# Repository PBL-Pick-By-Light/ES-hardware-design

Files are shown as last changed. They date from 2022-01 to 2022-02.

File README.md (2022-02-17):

# Hardware Design

## Introduction

Welcome to the hardware design repository of the Pick-by-Light projekt!

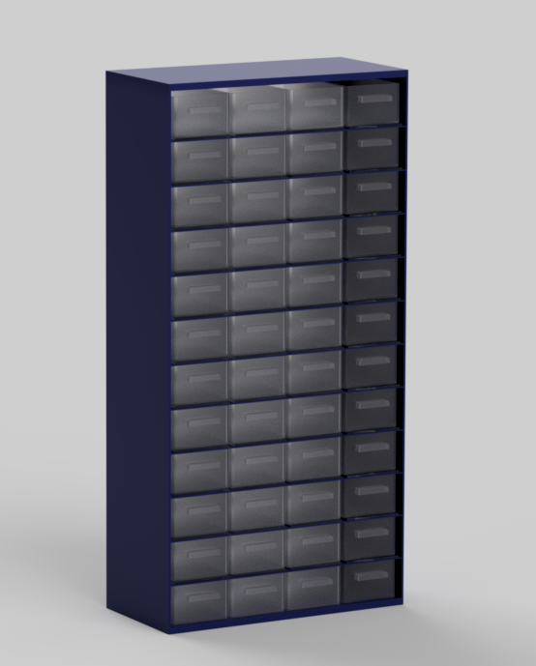
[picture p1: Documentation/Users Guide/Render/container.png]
Our implemented PBL system render


Our implemented PBL system real

The PBL project is designed to upgrade a small parts container with a microcontroller and LEDs.
In this repository you will find everything physically related to build the PBL, all software can be found in the other repositories.

In our implementation we installed the LEDs and the microcontroller via 3D printed parts and added acrylic glass sheets underneath each drawer to relay the emitted light of the LEDs. All necessary parts, further instructions to replicate our implementation and technical specs can be found in the [docs subfolder][docslink], also available as [PDF][UserGuidePDF] to print.

The PBL project is an open source project and we highly encourage you to modify and adjust everything to fit your needs. You can devise your own holding mechanisms and attachement of LEDs. The only necessity to work properly with the firmware is the usage of Adafruit adressable LEDs and an ESP32 microcontroller.

## Index

* [docs][docslink]
  - [Parts Listing](docs/PartsListingREADME.md)
  - [Technical Specs](docs/TechnicalSpecsREADME.md)
  - [Assembly and Installation](docs/AssemblyAndInstallationREADME.md)
* [Documentation][documentationlink]
* [Fusion360][fusionlink]
* [Master3DFiles][3dlink]

docs: all documentation about used hardware, which spare parts container we used and how to install everything to it as Readme files

Documentation: all files regarding documentation and complementing the users guide

Fusion360: Fusion360 project files to edit yourself to fit on different spare parts containers

Master3DFiles: all .stl and .obj files to put on a 3D printer

[docslink]:docs
[documentationlink]:Documentation
[fusionlink]:Fusion360
[3dlink]:Master3DFiles
[UserGuidePDF]:Documentation/PBL%20Users%20Guide.pdf

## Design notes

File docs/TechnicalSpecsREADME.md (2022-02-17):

# Technical Specifications

The PBL is powered by an ESP32 microcontroller to which the LEDs are connected. One
ESP32 corresponds to one sparepartscontainer, multiple ESP32s are connected via WIFI
to a single Raspberry Pi which holds the Frontend and Backend software structures.

Further information can be found in the [users guide](../Documentation/PBL%20Users%20Guide.pdf).

## Our used hardware

Microcontroller: NodeMCU ESP32
LEDs: Adafruit Flora Smart NeoPixel RGB LED v2 (WS2812B controller)

As for our attachement of LEDs we designed 3D printable parts to fit specifically:

Spare parts container: 30,5cm x 15cm x 55cm

Compartment/drawer: 7cm x 14cm x 4cm

12 rows, 4 compartments per row

two 3cm wide steelflaps on the backside of the container to hold the mechanisms with neodym magnets

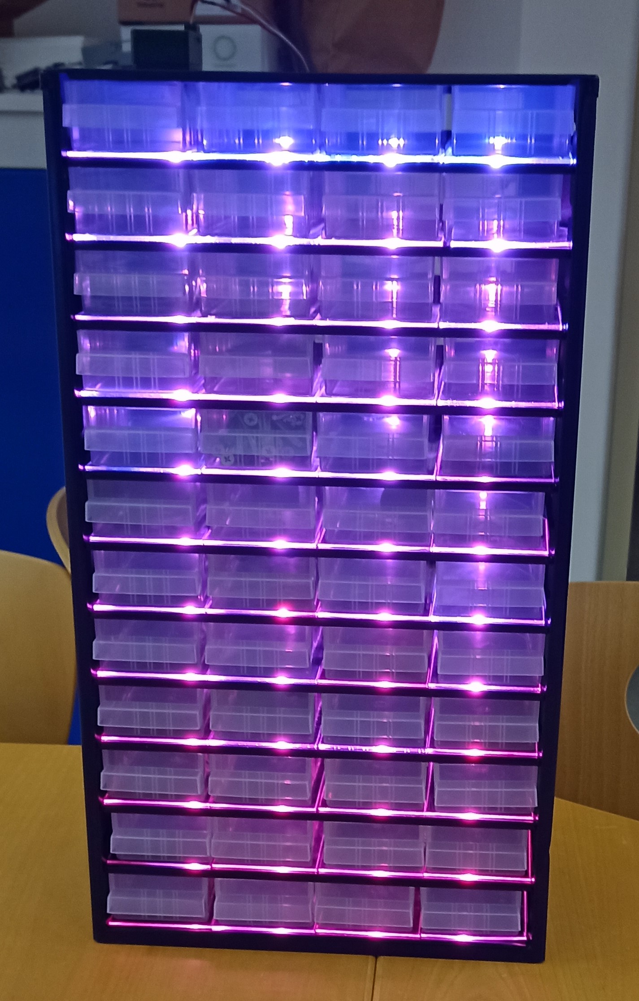
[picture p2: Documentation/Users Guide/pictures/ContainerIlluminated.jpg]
front
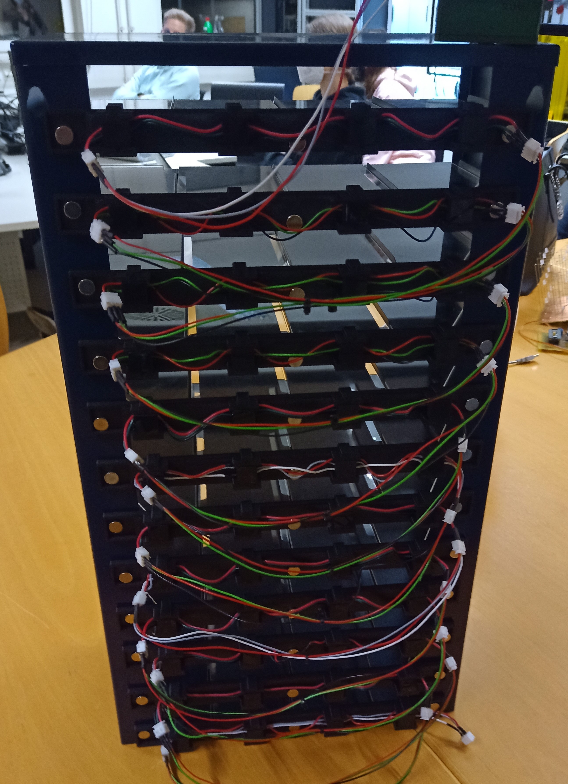
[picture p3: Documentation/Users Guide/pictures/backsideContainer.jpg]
back


## Wiring diagram

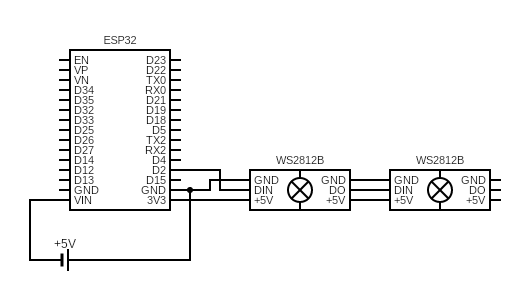
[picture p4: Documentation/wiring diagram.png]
Wiring Diagram


## Power consumption

(all specifications for Adafruit Flora Smart NeoPixel RGB LED v2)

One NeoPixel draws a maximum of 60mA if all color values are at 100%.
One sparepartscontainer with 48 compartments and so 48 LEDs draws a total of 2,9A at
3,3V.

Depending on how many compartments and LEDs you have per sparepartscontainer you
can either power the whole system via the ESP32's pins (as shown in the above wiring
diagram) or via a seperate powersupply. If you use the latter option make sure the ESP32
and the LEDs are connected to the same GROUND.

To find a suitable powersupply you can calculate the maximum power consumption of your
spare parts container with following formula:

60mA x (NumberOfLEDs) = Powerdrawage

The PBL system can only be powered by a maximum of 5V DC.

For further explanation of power consumption consult the [adafruit website](https://learn.adafruit.com/adafruit-neopixel-uberguide/powering-neopixels).

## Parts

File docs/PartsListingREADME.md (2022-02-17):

# Parts list

A list of parts needed to build the PBL on your own. This listing is specified for a single
sparepartscontainer with 12 rows and 4 compartments per row. The exact measurements can be found in the [Technical Specification](../docs/TechnicalSpecsREADME.md). 3D printed parts are marked with „(3DP)“. 

| ItemNr | Description | Qty. |
|-----|-----|-----|
| 1 | Spare parts container | 1 |
| 2 | ESP32 | 1 |
| 3 | Adafruit Flora Smart NeoPixel (or similar) | 48 |
| 4 | (3DP) LED Holding Mechanism | 12 |
| 5 | (3DP) LED Wedges | 48 |
| 6 | (3DP) LED Holding Mechanism Connector | 22 |
| 7 | (3DP) ESP Box | 1 |
| 8 | (3DP) ESP Box Lid | 1 |
| 9 | 10mm x 3mm Neodym Magnets | 60 |
| 10 | Acrylic glass sheets 1,5mm thickness (7cm x 14cm) *| 24 |
| 11 | Acrylic glass sheets wedged 1,5mm thickness (7cm x 14cm front, 3cm x 14cm back) * | 24 |
| 12 | Cable 1mm diameter (between LEDs) | 108 |
| 13 | Cable 1mm diameter (connectors end of row) | 72 |
| 14 | Cable 1mm diameter (connector between rows) | 36 |
| 15 | JST Male 3 pole | 23 |
| 16 | JST Female 3 pole | 24 |
| 17 | JST Crimpcontacts | 72 |
| 18 | Jumpercable Male (ESP32 connector) | 3 |

*specific measurements depend on your sparepartscontainer, the acrylic glass sheets need to lay flat underneath each
drawer.

Further description can be found in the [UserGuidePDF][Userguide].

[Userguide]:../Documentation/PBL%20Users%20Guide.pdf

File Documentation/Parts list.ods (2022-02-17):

ItemNr | Description | Quantity | Length | Combined |  | Qty raw material | Net € | gross € | Link
1 | Sparepartscontainer | 1 |  |  |  | 1 |  | 65,99 | https://www.conrad.de/de/p/raaco-1248-01-schubladenschrank-l-x-b-x-h-306-x-150-x-552-mm-anzahl-faecher-48-1-st-1597311.html
2 | ESP32 | 1 |  |  |  | 1 |  | 11,65 | https://www.reichelt.de/nodemcu-esp32-wifi-und-bluetooth-modul-debo-jt-esp32-p219897.html?trstct=pos_0&nbc=1
3 | Flora NeoPixel | 48 |  |  |  | 3 x sheet of 20 |  | 99,06 | https://www.exp-tech.de/zubehoer/led-leuchtmittel/5169/adafruit-flora-rgb-smart-neo-pixel-version-2-sheet-of-20
4 | (3DP) HoldingMechanism | 12
5 | (3DP) Wedges | 48
6 | (3DP) HoldingMechanismBinder | 22
7 | (3DP) ESPBox | 1
8 | (3DP) ESPBox Lid | 1 |  |  | 3D parts combined: | ?
9 | 10mm x 3mm Neodym magnets | 60 |  |  |  | 1 x 64 |  | 10,99 | https://www.amazon.de/Wukong-Magnettafel-Magnetstreifen-K%C3%BChlschrank-Magnetboards/dp/B0823T7QCR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
10 | Acrylic glass sheets 1,5mm (7cm x 14cm) | 24
11 | Acrylic glass sheets wedged 1,5mm (7cm x 14cm, one side 3cm x 14cm) | 24 |  |  | Acrylic glass combined: | 2 x (305x625mm) | 51,96 | 61,84 | https://de.rs-online.com/web/p/kunststoffplatten/7698724
12 | Cable 1mm diameter (between LEDs) | 108 | 8cm | 864cm
13 | Cable 1mm diameter (connectors end of row) | 72 | 3cm | 216cm
14 | Cable 1mm diameter (connector between rows) | 36 | 25cm | 900cm | Cable combined: | 2 x 10m |  | 5,72 | https://www.conrad.de/de/p/conrad-components-1180312-litze-lify-1-x-0-25-mm-gruen-gelb-10-m-1180312.html
15 | JST Male 3 pole | 23 |  |  |  | 23 |  | 2,3 | https://www.reichelt.de/jst-buchsengehaeuse-1x3-polig-xh-jst-xh3p-bu-p185086.html?trstct=pos_2&nbc=1
16 | JST Female 3 pole | 24 |  |  |  | 24 |  | 3,36 | https://www.reichelt.de/jst-stiftleiste-gerade-1x3-polig-xh-jst-xh3p-st-p185074.html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
17 | JST Crimpcontacts | 72 |  |  |  | 72 |  | 8,86 | https://www.reichelt.de/jst-crimpkontakt-buchse-xh-jst-xh-ckb-p185091.html?nbc=1&trstct=lsbght_sldr::185086
18 | JumperCable Male (connector ESP) | 3 | 10cm
 |  |  |  |  |  |  |  | 269,77

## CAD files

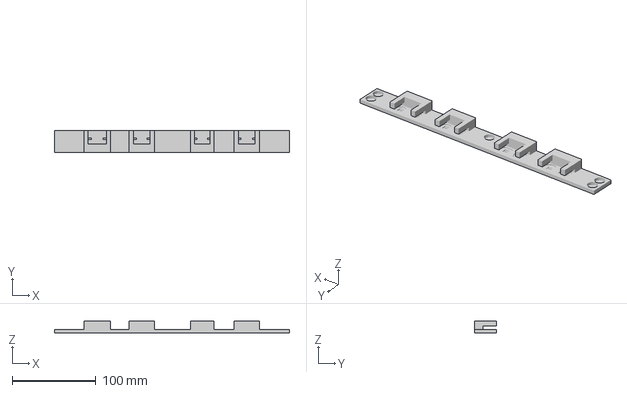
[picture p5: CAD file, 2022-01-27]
Documentation/Testing/LEDHoldingMechanismBackLEDTesting v1.3mf
280.0 x 26.0 x 14.0 mm

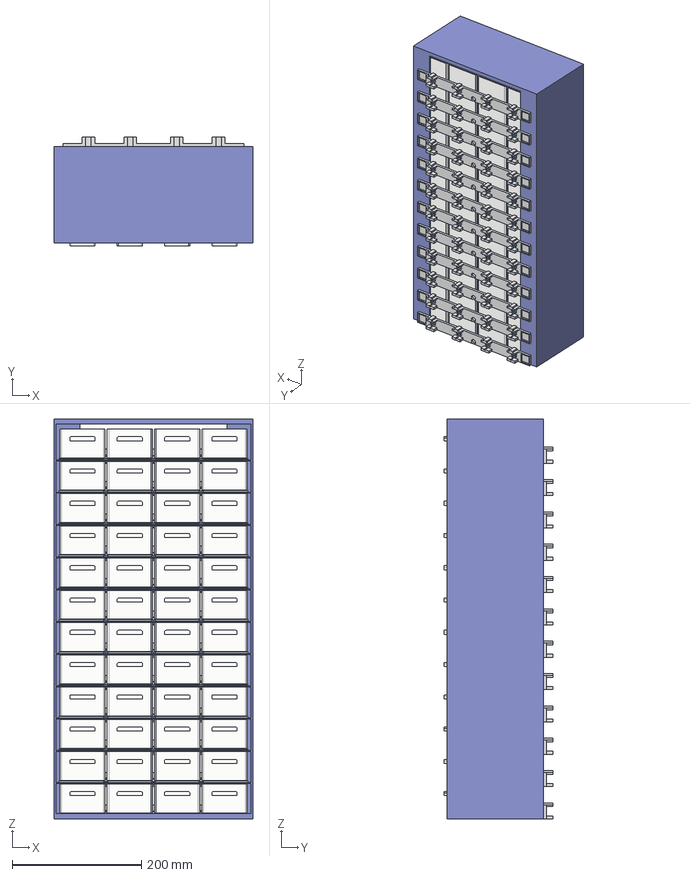
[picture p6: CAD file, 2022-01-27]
Fusion360/SmallPartsContainer.step
307.6 x 169.3 x 619.8 mm
Container
LEDHoldingMechanism x 12
Acryl
Scrank

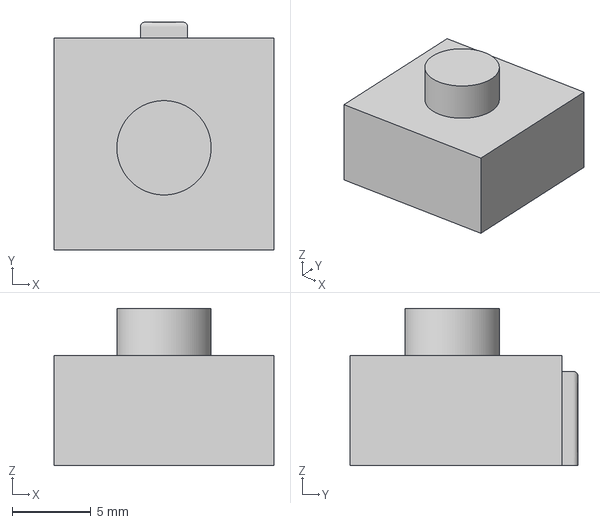
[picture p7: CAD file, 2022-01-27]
Master3DFiles/LEDClamp.3mf
14.0 x 14.5 x 10.0 mm

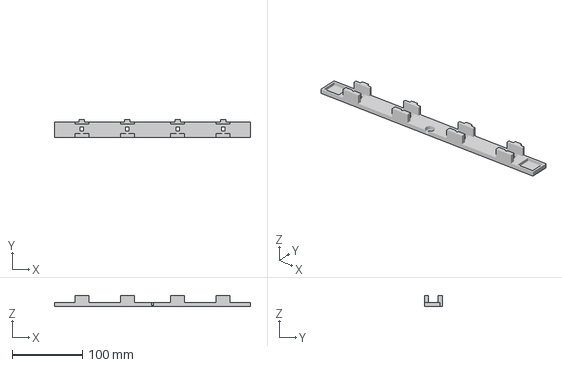
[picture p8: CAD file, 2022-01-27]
Master3DFiles/LEDHoldingMechanism.3mf
280.0 x 25.0 x 15.0 mm

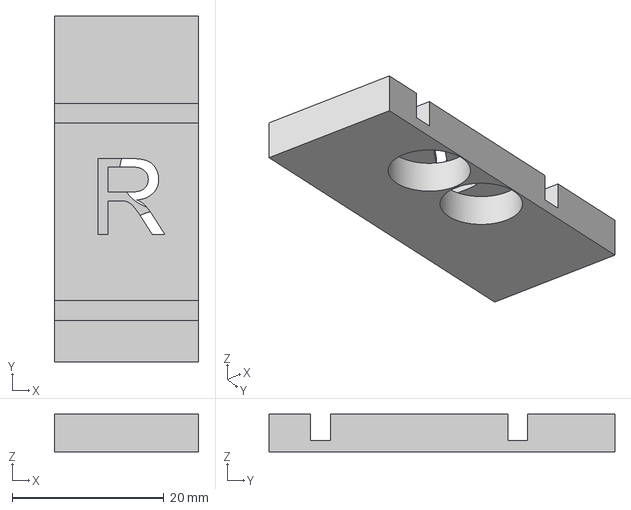
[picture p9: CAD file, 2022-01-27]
Master3DFiles/LEDHoldingMechanismBinderR.3mf
19.0 x 45.6 x 5.00 mm

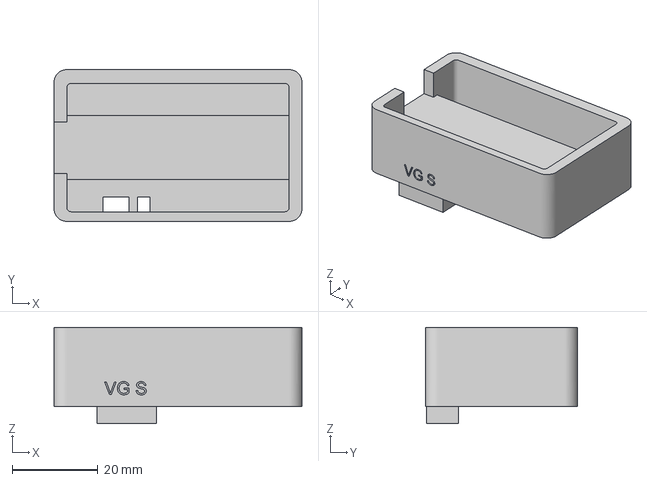
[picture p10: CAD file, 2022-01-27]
Master3DFiles/ESP32Box.3mf
58.0 x 35.5 x 22.5 mm

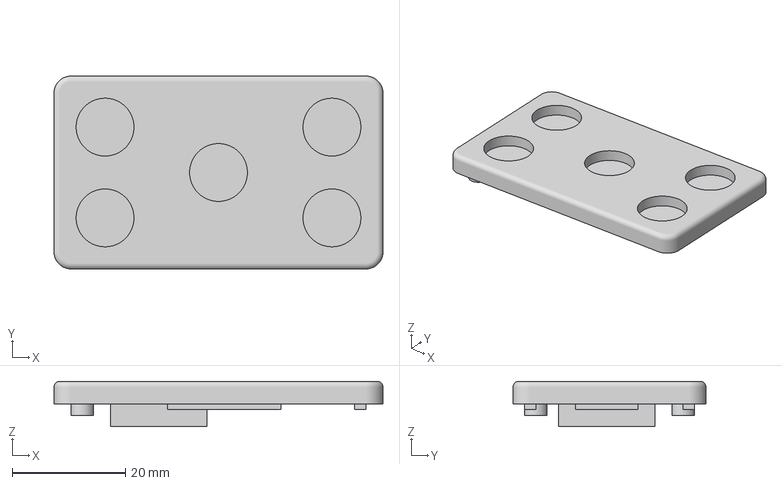
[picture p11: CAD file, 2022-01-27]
Master3DFiles/ESP32Lid.3mf
58.0 x 34.0 x 8.00 mm

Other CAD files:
Master3DFiles/LEDHoldingMechanismBinderL.3mf
Fusion360/ESPBox and Lid.f3d
Fusion360/LEDClamp.f3d
Fusion360/LEDHoldingMechanism.f3d
Fusion360/LEDHoldingMechanismBinderL.f3d
Fusion360/LEDHoldingMechanismBinderR.f3d
Master3DFiles/ESP32Box.stl
Master3DFiles/ESP32Lid.stl
Master3DFiles/LEDClamp.stl
Master3DFiles/LEDHoldingMechanism.stl
Master3DFiles/LEDHoldingMechanismBinderL.stl
Master3DFiles/LEDHoldingMechanismBinderR.stl

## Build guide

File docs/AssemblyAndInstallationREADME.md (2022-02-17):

# Assembly

Before you begin replicating our implementation of the PBL make sure you have all necessary parts and that they are fitting to your spare parts container. You can find a listing of all parts [here](../docs/PartsListingREADME.md) and the specifications of the spare parts container [here](../docs/TechnicalSpecsREADME.md).

Further information can be found in the [users guide](../Documentation/PBL%20Users%20Guide.pdf).

## Soldering the LEDs

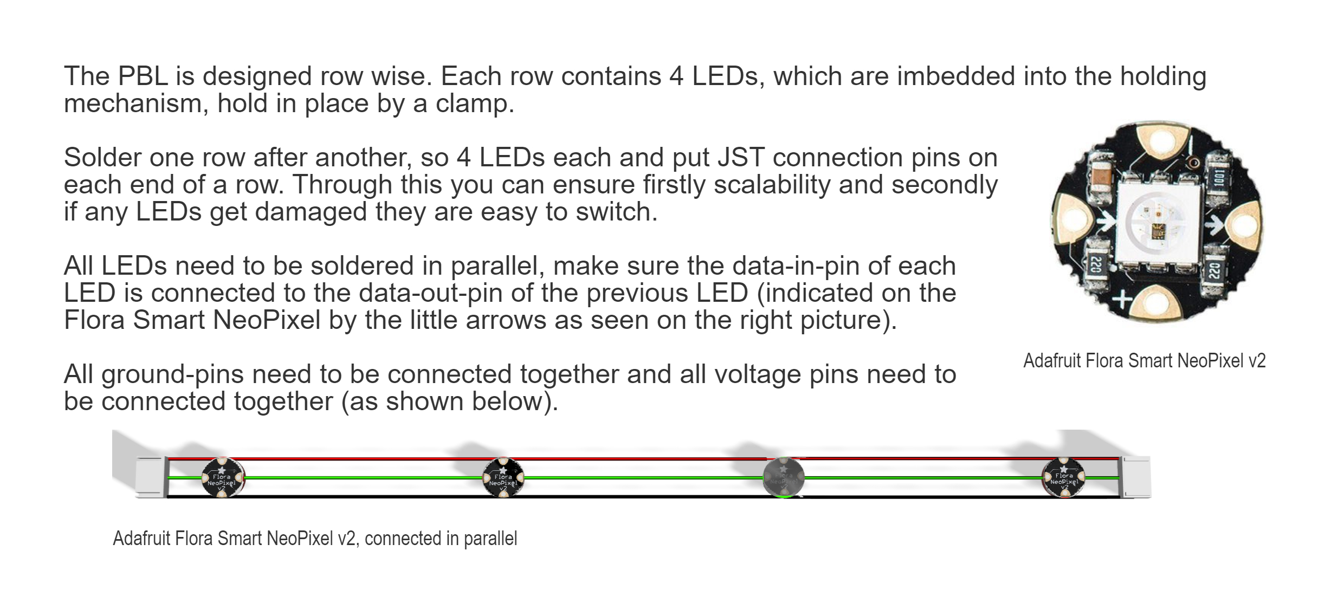
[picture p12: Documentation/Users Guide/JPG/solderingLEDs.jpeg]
leds soldered picture


## Installation of LEDs to holding mechanisms

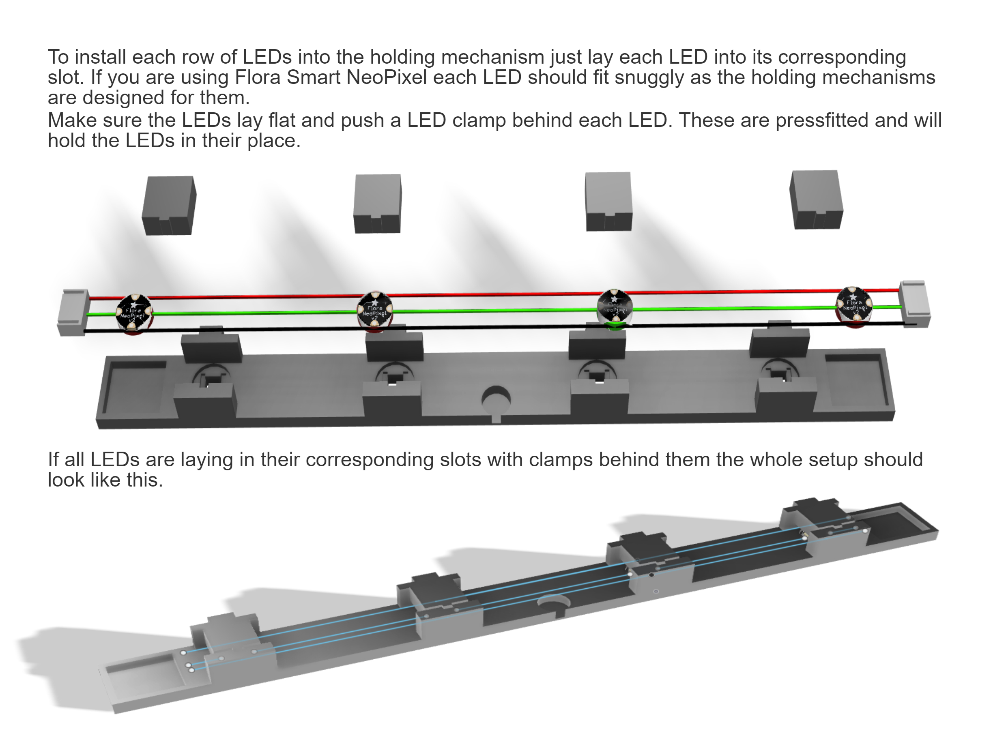
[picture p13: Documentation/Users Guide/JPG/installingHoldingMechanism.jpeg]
installation of leds to holding mechanism


## Assembly and attachment of acrylsheets

Make sure your acrylic glass sheets are thin enough so each compartment can still be drawn outwards.

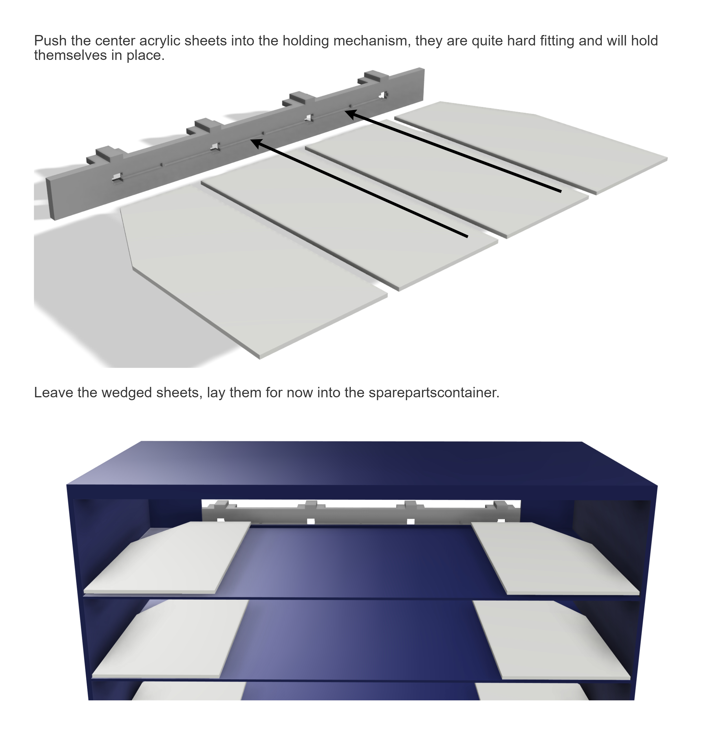
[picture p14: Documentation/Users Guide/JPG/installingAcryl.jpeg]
Assembly of acryl sheets


## Installing the holding mechanisms

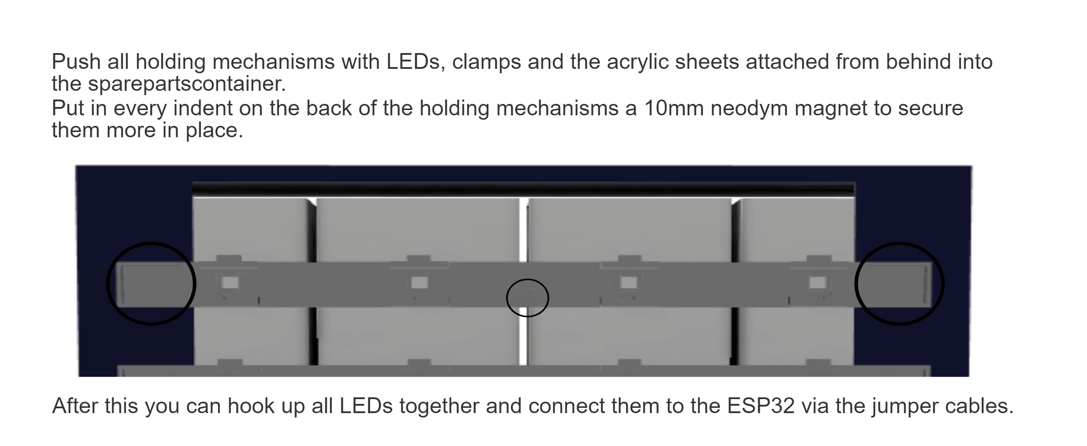
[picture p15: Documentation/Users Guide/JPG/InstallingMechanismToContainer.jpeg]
installation of holding mechanisms


When everything is installed it should look something like this:

Backside small parts container

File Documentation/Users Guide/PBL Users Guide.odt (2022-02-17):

Softwaretechnik Projekt WS21/22, Jakob Czekansky

User Guide Hardware

Pick-by-Light

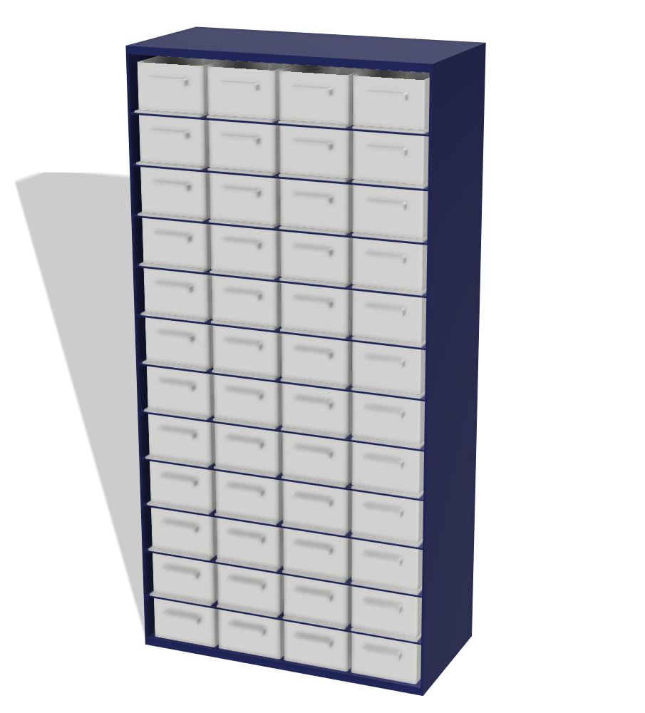
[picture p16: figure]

# Introduction

Welcome to the Pick-By-Light system!

The Pick-By-Light System (hereinafter called PBL) is a system to assist you in finding spareparts in multiple rooms and small parts magazin in them. To achieve this the PBL provides a graphical user interface on your smart device or web browser in which you search for a specific sparepart. The compartment, in which the part is stored, will light up.

This project is an open source project and we highly encourage you to build it on your own and modify the hard- or software to your likings. To ensure you are able to do this you will find all relevant information on which parts you need to build it on your own, the technical specifications and an assembly guide in this document.

Some of the parts need to be 3D printed, you can find all necessary 3D printable master files in the git repository.

# Parts List

A list of parts needed to build the PBL on your own. This listing is specified for a single sparepartscontainer with 12 rows and 4 compartments per row. 3D printed parts are marked with „(3DP)“.

ItemNr | Description | Qty. | Length (if needed)
1 | Sparepartscontainer | 1
2 | ESP32 Microcontroller | 1
3 | Adafruit Flora Smart NeoPixel (or similar) | 48
4 | (3DP) LED Holding Mechanism | 12
5 | (3DP) LED Wedges | 48
6 | (3DP) LED Holding Mechanism Connector | 22
7 | (3DP) ESP Box | 1
8 | (3DP) ESP Box Lid | 1
9 | 10mm x 3mm Neodym Magnets | 60
10 | Acrylic glass sheets 1,5mm thickness (7cm x 14cm) * | 24
11 | Acrylic glass sheets wedged 1,5mm thickness (7cm x 14cm front, 3cm x 14cm back) * | 24
12 | Cable 1mm diameter (between LEDs) | 108 | 8cm
13 | Cable 1mm diameter (connectors end of row) | 72 | 3cm
14 | Cable 1mm diameter (connector between rows) | 36 | 30cm
15 | JST Male 3 pole | 23
16 | JST Female 3 pole | 24
17 | JST Crimpcontacts | 72
18 | Jumpercable Male (ESP32 connector) | 3 | 10cm

*specific measurements depend on your sparepartscontainer, the acrylic glass sheets need to lay flat underneath each drawer.

# Technical Specifications

The PBL is powered by an ESP32 microcontroller to which the LEDs are connected. One ESP32 corresponds to one sparepartscontainer, multiple ESP32s are connected via WIFI to a single Raspberry Pi which holds the Frontend and Backend software structures.

In the following datasheet only the hardware components of one sparepartscontainer will be discussed.

## Used hardware

Microcontroller: ESP32

LEDs: Adafruit Flora Smart NeoPixel RGB LED v2 (WS2812B controller)

## Wiring Diagram


## Power Consumption

One NeoPixel draws a maximum of 60mA if all color values are at 100%.

One sparepartscontainer with 48 compartments and so 48 LEDs draws a total of 2,9A at 3,3V.

Depending on how many compartments and LEDs you have per sparepartscontainer you can either power the whole system via the ESP32's pins (as shown in the above wiring diagram) or via a seperate powersupply. If you use the latter option make sure the ESP32 and the LEDs are connected to the same GROUND.

To find a suitable powersupply you can calculate the maximum power consumption of your sparepartscontainer with following formula:

60mA x (NumberOfLEDs) = Powerdrawage

The PBL system can only be powered by a maximum of 5V DC.

For further explanation of power consumption consult the adafruit website:

https://learn.adafruit.com/adafruit-neopixel-uberguide/powering-neopixels

# Assembly Guide

## Soldering the LEDs


## Installation of LEDs to holding mechanisms


## Assembly and attachment of acrylsheets and installing the holding mechanisms to the sparepartscontainer


# Testing

LEDs tested:

RGB Smart NeoPixel

Flora NeoPixel

"in house" LEDs

Best luminoscity/color purity: Flora NeoPixel

Cablelength tested: 10m before first LED, LEDs still working.

Nearly noticable difference between single and double LEDs per compartment.

Further information on the LEDs luminoscity can be found in the git repository.

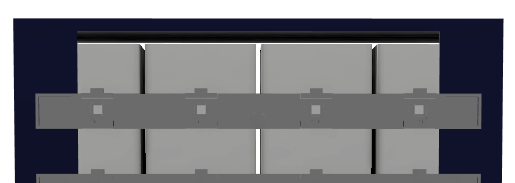
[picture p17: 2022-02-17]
Documentation/Users Guide/Render/BackSingleRow.png

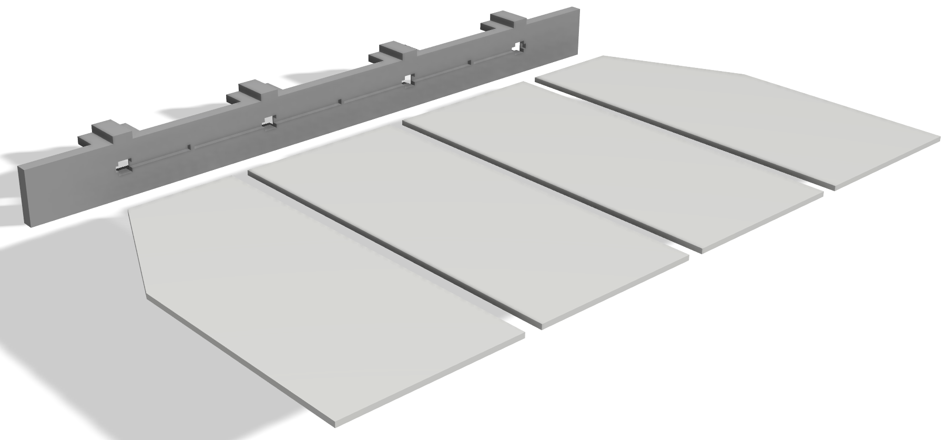
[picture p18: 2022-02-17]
Documentation/Users Guide/Render/AcrylIntoRow.png

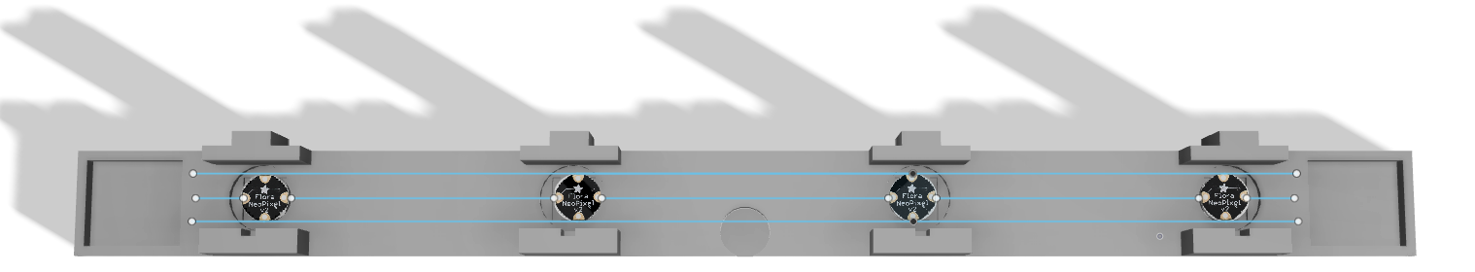
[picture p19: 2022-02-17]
Documentation/Users Guide/Render/LEDsinHoldingMechanism.png

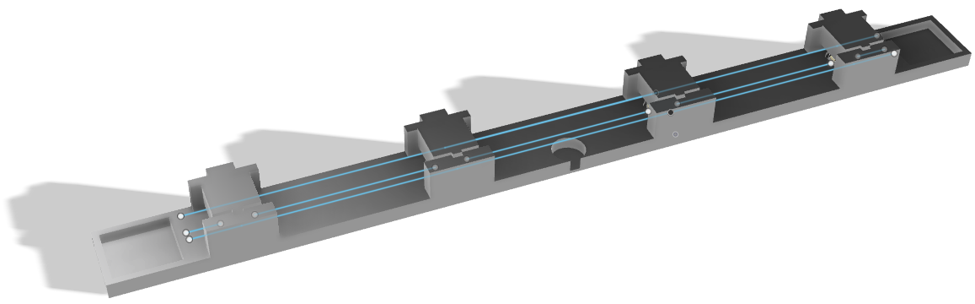
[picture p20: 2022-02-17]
Documentation/Users Guide/Render/HoldingMechanism+LEDs.png

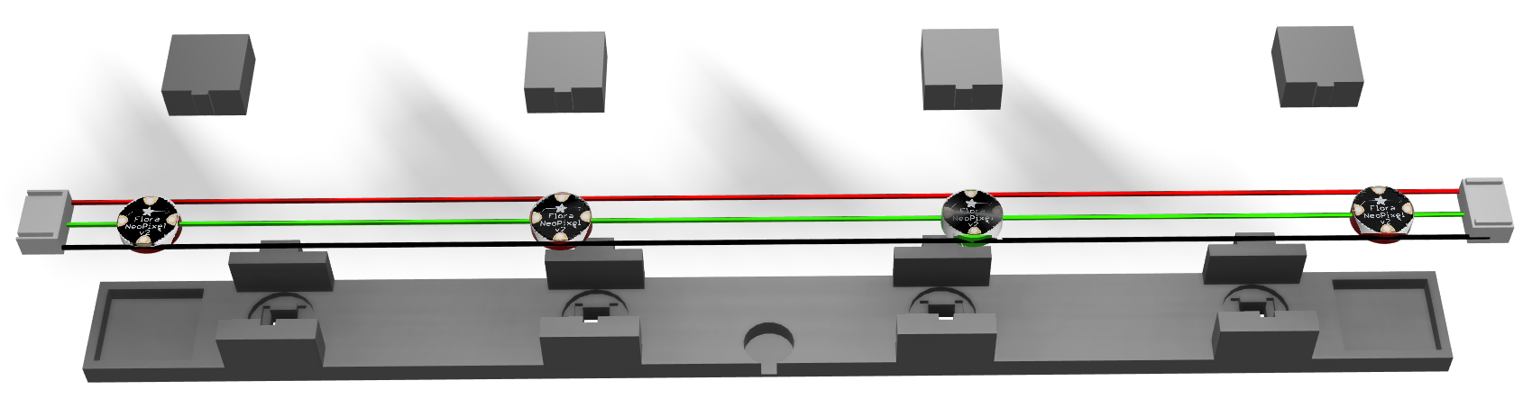
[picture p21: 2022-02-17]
Documentation/Users Guide/Render/RowStripeClamps.png

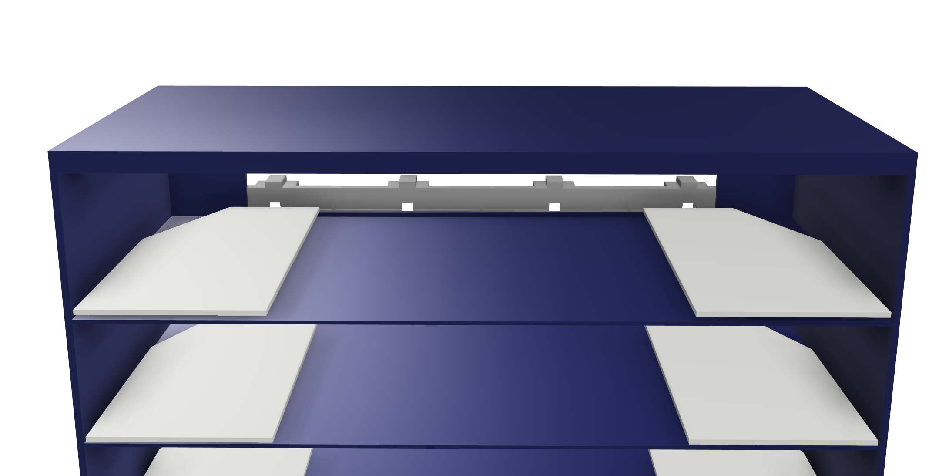
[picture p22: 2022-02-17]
Documentation/Users Guide/Render/AcrylIntoContainer.png

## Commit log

2022-02-17 initial new move commit
    [ESP32Box.3mf, ESP32Box.stl, ESP32Lid.3mf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]
2022-02-17 Renamed pictures
    [SmallPartsContainer.step]
